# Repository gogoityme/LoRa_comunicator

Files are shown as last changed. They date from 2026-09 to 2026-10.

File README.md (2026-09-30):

# LoRa-comunicator

**For some reason I cant upload .history files to this repo so I uploaded it here: https://drive.google.com/drive/folders/1uOQKTIaHVd6gNlLYLUI4MQFI1cR0wfdA?usp=drive_link**

**Something about this project**

Okay so it all started with me watching some videos about meshcore and meshtastic. So I ordered one simple module (seeed studio xiao with LoRa module). Then I wanted something that would be like a standalone device with keyboard. I looked at some T-decks and told myself that it is quite expensive. So I started designing my own. That two versions that I made are using the same components so the BOM is the same but version V1.1 is using 5 more switches and diodes because of keyboard layout. And also the case would be aviliable on makerworld and in this repo (also with modified meshcore firmware) after I test the phisical product and I would have the rigt dimensions (I dont want to use dimensions shown on product websites, I simply dont trust them). BTW pictures are only from V1.1 because I think that this version is better.

**Build**

I have not ordered it yet but here would be updates 
All the placings you can do with BOM as reference.

# Some pictures from CAD and 3Drender

**Power management**

Snímka obrazovky 2026-09-27 191950

**Main "brain"**

Snímka obrazovky 2026-09-27 191911

**Keyboard**

Snímka obrazovky 2026-09-29 162724

**And 3D render with PCB-design**

Snímka obrazovky 2026-09-29 162827

Snímka obrazovky 2026-09-29 162906

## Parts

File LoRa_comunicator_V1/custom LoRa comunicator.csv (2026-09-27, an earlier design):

Reference | Qty | Value | Footprint | Price | Link
BT1 | 1 | Battery | Connector_JST:JST_PH_B2B-PH-K_1x02_P2.00mm_Vertical | 8€ | https://soldered.com/products/li-po-battery-2100mah-3-7v-903759-jst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
C1,C2 | 2 | 10nF | Capacitor_SMD:C_0805_2012Metric_Pad1.18x1.45mm_HandSolder | 0,03€ | https://www.tme.eu/sk/details/cl21b103kbannnc/kondenzatory-mlcc-smd/samsung/
C3 | 1 | 100nF | Capacitor_SMD:C_0805_2012Metric_Pad1.18x1.45mm_HandSolder | 0,03€ | https://www.tme.eu/sk/details/0805b104k500ct/kondenzatory-mlcc-smd/walsin/
D1,D2,D3,D4,D5,D6,D7,D8,D9,D10,D11,D12,D13,D14,D15,D16,D17,D18,D19,D20,D21,D22,D23,D24,D25,D26,D27,D28,D29,D30,D31,D32,D33,D34,D35,D36,D37,D38,D39,D40,D41,D42,D43,D44,D45 | 45 | D | Diode_SMD:D_SOD-123 | 0,1€ | https://www.tme.eu/sk/details/b140hw-7/diody-schottky-smd/diodes-incorporated/
D46 | 1 | 1N5819WS | Diode_SMD:D_SOD-123 | 0,1€ | https://www.tme.eu/sk/details/b140hw-7/diody-schottky-smd/diodes-incorporated/
J1 | 1 | USB_C_Receptacle_USB2.0_14P | Connector_USB:USB_C_Receptacle_G-Switch_GT-USB-7010ASV | 1,50€ | https://www.tme.eu/sk/details/usbc31srasmtbk/konektory-usb-a-ieee1394/adam-tech/usb-c31-s-ra-smt-bk/
Q1 | 1 | AO3401A | Package_TO_SOT_SMD:SOT-23 | 0,2 | https://www.tme.eu/sk/details/ao3401a/tranzistory-s-kanalom-p-smd/alpha-omega-semiconductor/
R1,R2 | 2 | 5.1k | Resistor_SMD:R_0805_2012Metric_Pad1.20x1.40mm_HandSolder | 0,018€ | https://www.tme.eu/sk/details/erj6geyj512v/rezistory-smd/panasonic/
R3 | 1 | 2.4k | Resistor_SMD:R_0805_2012Metric_Pad1.20x1.40mm_HandSolder | 0,015€ | https://www.tme.eu/sk/details/wr08x2401ftl/rezistory-smd/walsin/
R4,R5 | 2 | 4.7k | Resistor_SMD:R_0805_2012Metric_Pad1.20x1.40mm_HandSolder | 0,016€ | https://www.tme.eu/sk/details/wr08x4701ftl/rezistory-smd/walsin/
R6,R7,R8 | 3 | 10k | Resistor_SMD:R_0805_2012Metric_Pad1.20x1.40mm_HandSolder | 0,06€ | https://www.tme.eu/sk/details/erjp06f1002v/rezistory-smd/panasonic/
R9 | 1 | 100k | Resistor_SMD:R_0805_2012Metric_Pad1.20x1.40mm_HandSolder | 0,05€ | https://www.tme.eu/sk/details/arm05btcw1003a/rezistory-smd/viking/
SW1,SW2,SW3,SW4,SW5,SW6,SW7,SW8,SW9,SW10,SW11,SW12,SW13,SW14,SW15,SW16,SW17,SW18,SW19,SW20,SW21,SW22,SW23,SW24,SW25,SW26,SW27,SW28,SW29,SW30,SW31,SW32,SW33,SW34,SW35,SW36,SW37,SW38,SW39,SW40,SW41,SW42,SW43,SW44,SW45 | 45 | SW_Push | Button_Switch_SMD:SW_SPST_TL3342 | 0,4€ | https://www.tme.eu/sk/details/tl3342f160qg/mikrospinace-tact/e-switch/
U1 | 1 | TP4056-42-ESOP8 | Package_SO:SOIC-8-1EP_3.9x4.9mm_P1.27mm_EP2.41x3.3mm_ThermalVias | 0,19€ | https://techfun.sk/produkt/nabijaci-modul-tp4056-samostatny-cip-sop8-1a/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
U2 | 1 | AP2112K-3.3 | Package_TO_SOT_SMD:SOT-23-5 | 0,2€ | https://www.tme.eu/sk/details/ap2112k-3.3trg1/stabilizatory-napatia-neregulovane-ldo/diodes-incorporated/
U3 | 1 | HT-CT62 | RF_Module:Heltec_HT-CT62 | 7€ | https://heltec.org/project/ht-ct62/
U4 | 1 | TCA8418RTWR | Package_DFN_QFN:QFN-24-1EP_4x4mm_P0.5mm_EP2.15x2.15mm | 1,22€ | https://www.mouser.sk/en/ProductDetail/Texas-Instruments/TCA8418RTWR?qs=OaSNdy%2FNfznRf6fiHyMJcA%3D%3D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
U5 | 1 | ER_OLEDM0.91_1x-I2C | SSD1306:128x64OLED | 3,45€ | https://www.drotik-elektro.sk/arduino-platforma/1569-iic-i2c-oled-displej-0-96-biely-128-x-64.html?cv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
U6 | 1 | USBLC6-2SC6 | Package_TO_SOT_SMD:SOT-23-6 | 0,26€ | https://www.tme.eu/sk/details/usblc6-2sc6/bezpecnostne-diody-rebriky/stmicroelectronics/

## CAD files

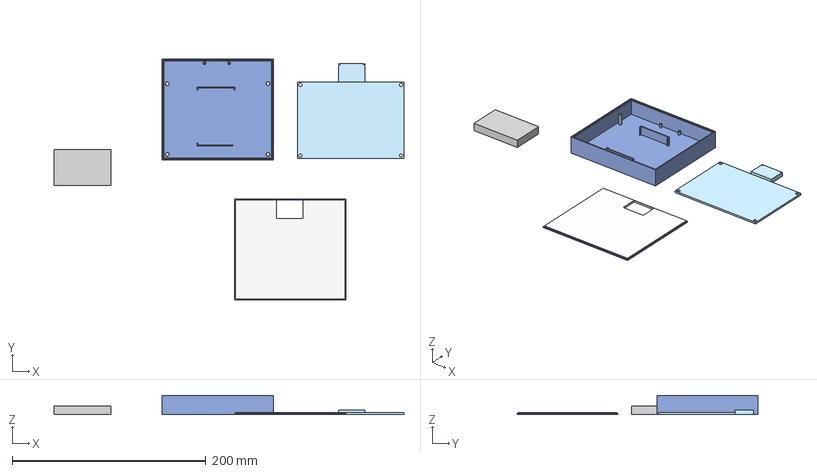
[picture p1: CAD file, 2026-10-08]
all parts.step
361.4 x 248.9 x 20.0 mm

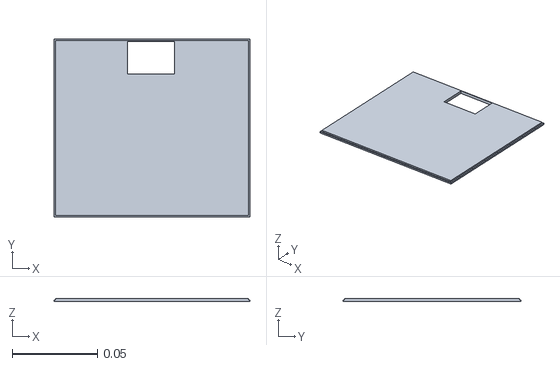
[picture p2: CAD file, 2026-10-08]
enclosure/top enclosure.stl
0.115 x 0.104 x 0.002

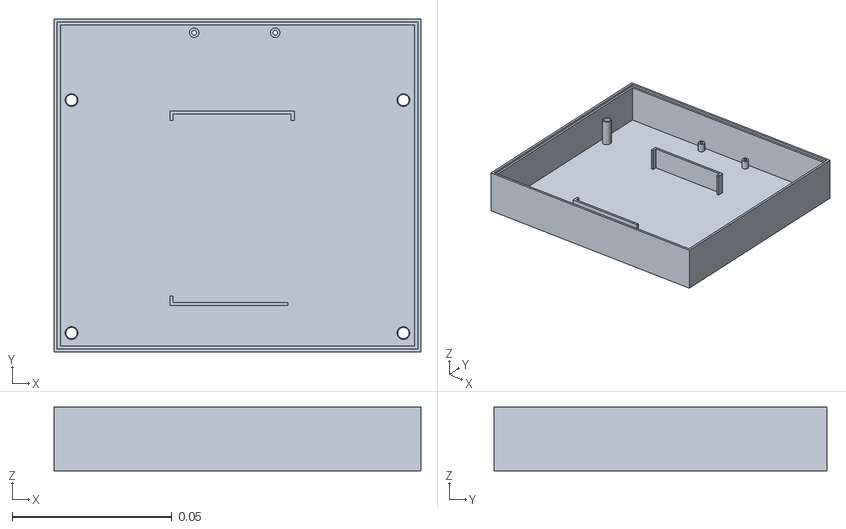
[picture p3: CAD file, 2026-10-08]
enclosure/bottom enclosure.stl
0.115 x 0.104 x 0.02

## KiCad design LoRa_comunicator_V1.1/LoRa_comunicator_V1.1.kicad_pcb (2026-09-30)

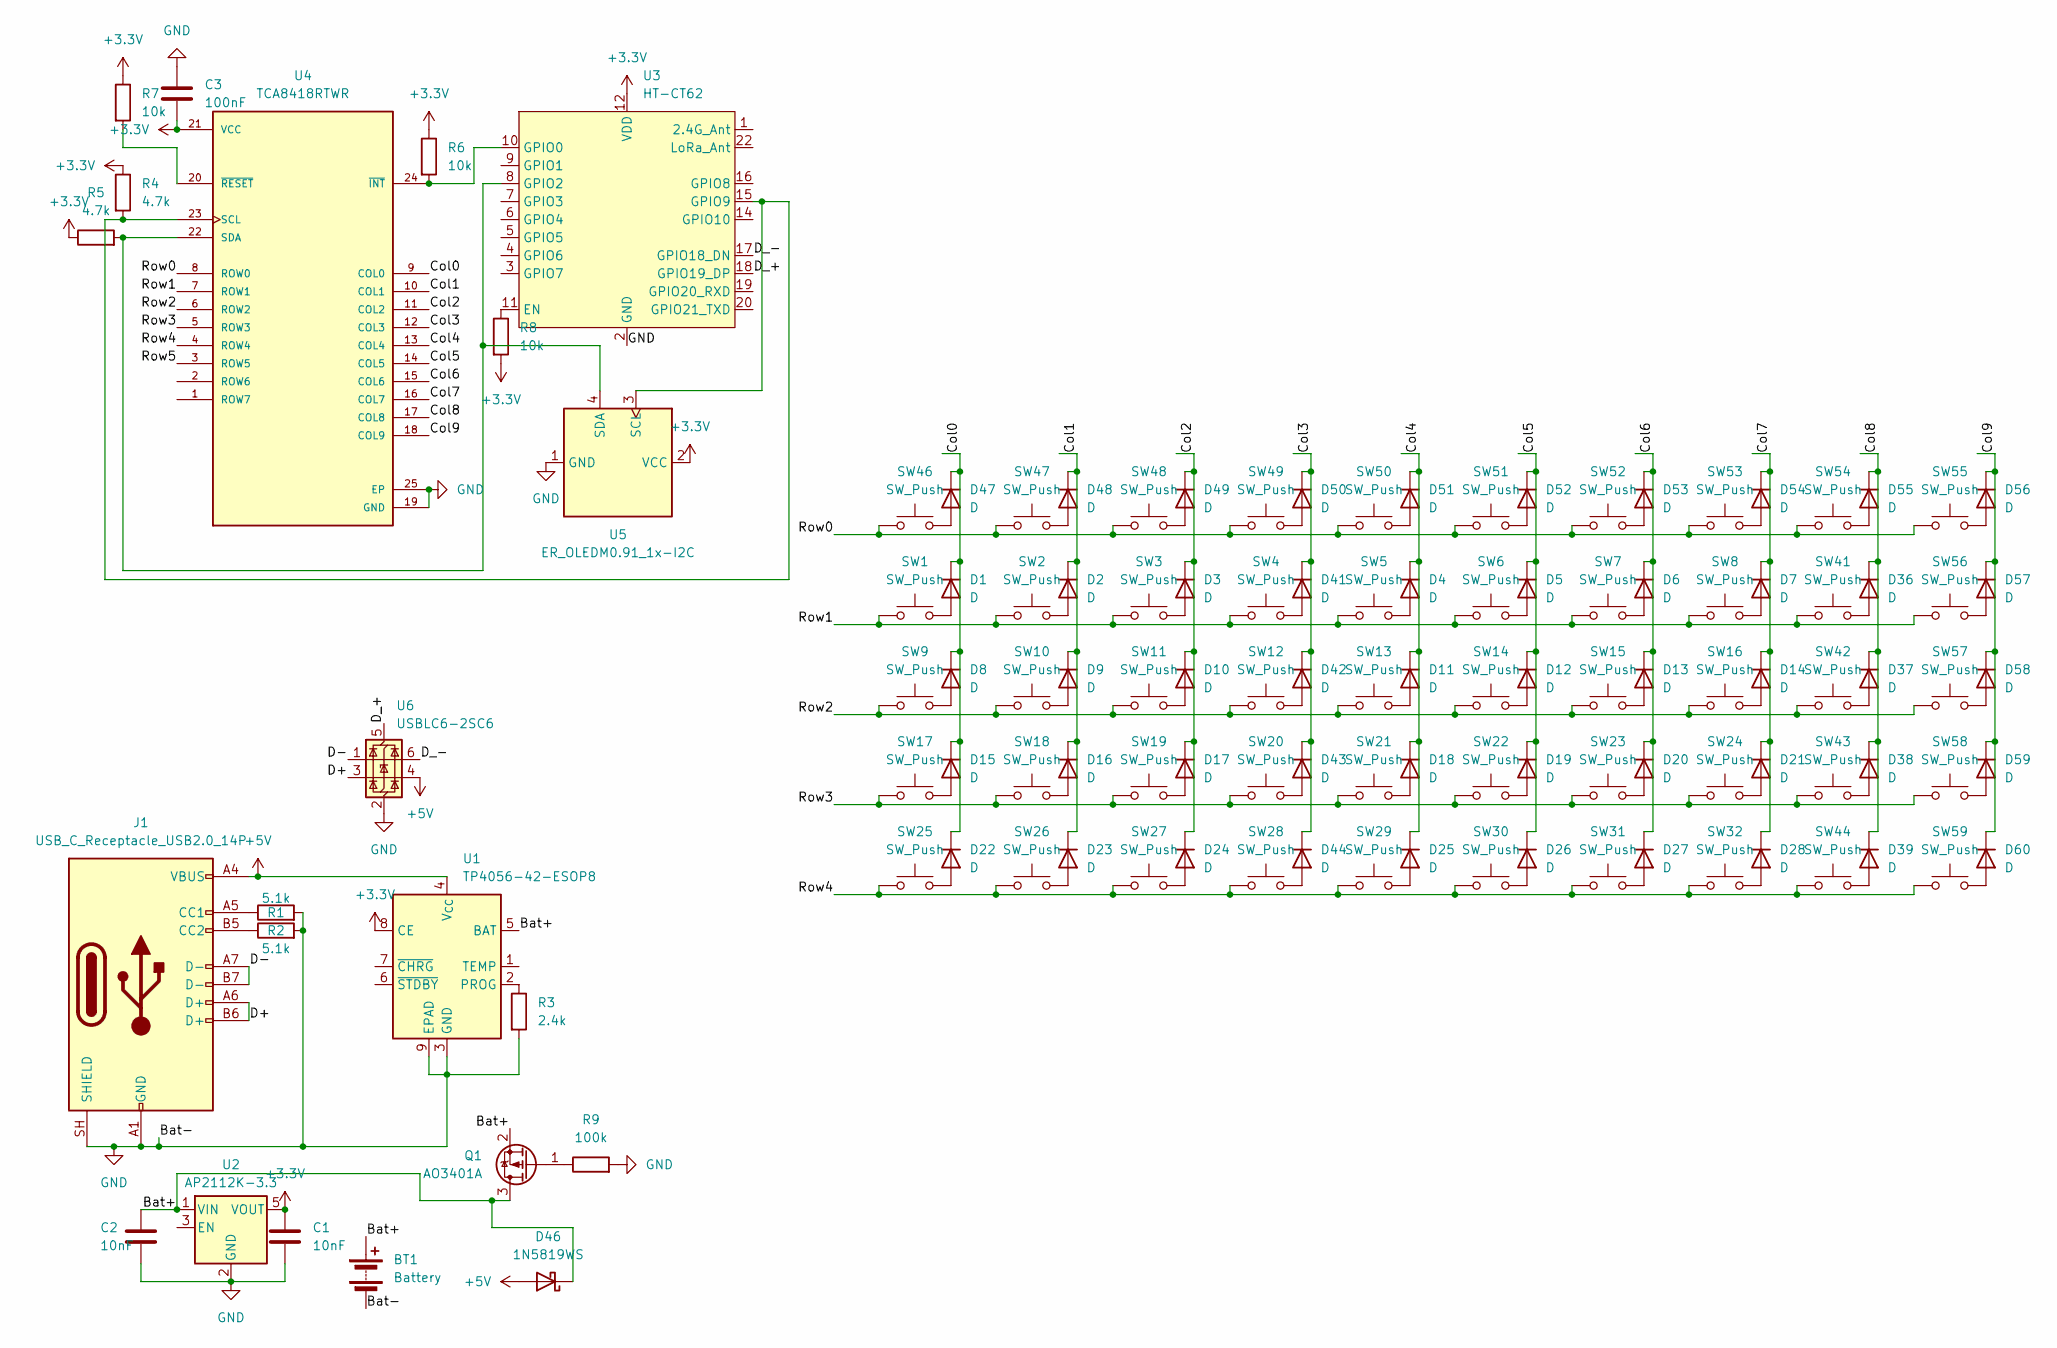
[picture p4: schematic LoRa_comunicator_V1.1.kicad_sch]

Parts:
BT1: Battery; JST_PH_B2B-PH-K_1x02_P2.00mm_Vertical
C1, C2: 10nF; C_0805_2012Metric_Pad1.18x1.45mm_HandSolder
C3: 100nF; C_0805_2012Metric_Pad1.18x1.45mm_HandSolder
D1, D2, D3, D4, D5, D6, D7, D8, D9, D10, D11, D12, D13, D14, D15, D16, D17, D18, D19, D20, D21, D22, D23, D24, D25, D26, D27, D28, D36, D37, D38, D39, D41, D42, D43, D44, D47, D48, D49, D50, D51, D52, D53, D54, D55, D56, D57, D58, D59, D60: D; D_SOD-123
D46: 1N5819WS; D_SOD-123
J1: USB_C_Receptacle_USB2.0_14P; USB_C_Receptacle_G-Switch_GT-USB-7010ASV
Q1: AO3401A; SOT-23
R1, R2: 5.1k; R_0805_2012Metric_Pad1.20x1.40mm_HandSolder
R3: 2.4k; R_0805_2012Metric_Pad1.20x1.40mm_HandSolder
R4, R5: 4.7k; R_0805_2012Metric_Pad1.20x1.40mm_HandSolder
R6, R7, R8: 10k; R_0805_2012Metric_Pad1.20x1.40mm_HandSolder
R9: 100k; R_0805_2012Metric_Pad1.20x1.40mm_HandSolder
SW1, SW2, SW3, SW4, SW5, SW6, SW7, SW8, SW9, SW10, SW11, SW12, SW13, SW14, SW15, SW16, SW17, SW18, SW19, SW20, SW21, SW22, SW23, SW24, SW25, SW26, SW27, SW28, SW29, SW30, SW31, SW32, SW41, SW42, SW43, SW44, SW46, SW47, SW48, SW49, SW50, SW51, SW52, SW53, SW54, SW55, SW56, SW57, SW58, SW59: SW_Push; SW_SPST_TL3342
U1: TP4056-42-ESOP8; SOIC-8-1EP_3.9x4.9mm_P1.27mm_EP2.41x3.3mm_ThermalVias
U2: AP2112K-3.3; SOT-23-5
U3: HT-CT62; Heltec_HT-CT62
U4: TCA8418RTWR; QFN-24-1EP_4x4mm_P0.5mm_EP2.15x2.15mm; PARTREV G
U5: ER_OLEDM0.91_1x-I2C; 128x64OLED
U6: USBLC6-2SC6; SOT-23-6

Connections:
+3.3V: C1.1, C3.2, R4.1, R5.1, R6.1, R7.1, R8.2, U1.8 (CE), U2.5 (VOUT), U3.12 (VDD), U4.21 (VCC), U5.2 (VCC)
+5V: D46.2 (A), J1.A4 (VBUS), J1.A9 (VBUS), J1.B4 (VBUS), J1.B9 (VBUS), U1.4 (V_{CC}), U6.4 (I/O2)
/Bat+: BT1.1 (+), C2.1, D46.1 (K), Q1.2 (S), Q1.3 (D), U1.5 (BAT), U2.1 (VIN)
/Col0: D1.1 (K), D8.1 (K), D15.1 (K), D22.1 (K), D47.1 (K), U4.9 (COL0)
/Col1: D2.1 (K), D9.1 (K), D16.1 (K), D23.1 (K), D48.1 (K), U4.10 (COL1)
/Col2: D3.1 (K), D10.1 (K), D17.1 (K), D24.1 (K), D49.1 (K), U4.11 (COL2)
/Col3: D41.1 (K), D42.1 (K), D43.1 (K), D44.1 (K), D50.1 (K), U4.12 (COL3)
/Col4: D4.1 (K), D11.1 (K), D18.1 (K), D25.1 (K), D51.1 (K), U4.13 (COL4)
/Col5: D5.1 (K), D12.1 (K), D19.1 (K), D26.1 (K), D52.1 (K), U4.14 (COL5)
/Col6: D6.1 (K), D13.1 (K), D20.1 (K), D27.1 (K), D53.1 (K), U4.15 (COL6)
/Col7: D7.1 (K), D14.1 (K), D21.1 (K), D28.1 (K), D54.1 (K), U4.16 (COL7)
/Col8: D36.1 (K), D37.1 (K), D38.1 (K), D39.1 (K), D55.1 (K), U4.17 (COL8)
/Col9: D56.1 (K), D57.1 (K), D58.1 (K), D59.1 (K), D60.1 (K), U4.18 (COL9)
/D+: J1.A6 (D+), J1.B6 (D+), U6.3 (I/O2)
/D-: J1.A7 (D-), J1.B7 (D-), U6.1 (I/O1)
/D_+: U3.18 (GPIO19_DP), U6.5 (VBUS)
/D_-: U3.17 (GPIO18_DN), U6.6 (I/O1)
/Row0: SW46.1, SW47.1, SW48.1, SW49.1, SW50.1, SW51.1, SW52.1, SW53.1, SW54.1, SW55.1, U4.8 (ROW0)
/Row1: SW1.1, SW2.1, SW3.1, SW4.1, SW5.1, SW6.1, SW7.1, SW8.1, SW41.1, SW56.1, U4.7 (ROW1)
/Row2: SW9.1, SW10.1, SW11.1, SW12.1, SW13.1, SW14.1, SW15.1, SW16.1, SW42.1, SW57.1, U4.6 (ROW2)
/Row3: SW17.1, SW18.1, SW19.1, SW20.1, SW21.1, SW22.1, SW23.1, SW24.1, SW43.1, SW58.1, U4.5 (ROW3)
/Row4: SW25.1, SW26.1, SW27.1, SW28.1, SW29.1, SW30.1, SW31.1, SW32.1, SW44.1, SW59.1, U4.4 (ROW4)
/Row5: U4.3 (ROW5)
GND: BT1.2 (-), C1.2, C2.2, C3.1, J1.A1 (GND), J1.A12 (GND), J1.B1 (GND), J1.B12 (GND), J1.SH (SHIELD), R1.2, R2.2, R3.2, R9.2, U1.3 (GND), U1.9 (EPAD), U2.2 (GND), U3.2 (GND), U3.13 (GND), U3.21 (GND), U4.19 (GND), U4.25 (EP), U5.1 (GND), U6.2 (GND)
unnamed: D1.2 (A), SW1.2
unnamed: D2.2 (A), SW2.2
unnamed: D3.2 (A), SW3.2
unnamed: D4.2 (A), SW5.2
unnamed: D5.2 (A), SW6.2
unnamed: D6.2 (A), SW7.2
unnamed: D7.2 (A), SW8.2
unnamed: D8.2 (A), SW9.2
unnamed: D9.2 (A), SW10.2
unnamed: D10.2 (A), SW11.2
unnamed: D11.2 (A), SW13.2
unnamed: D12.2 (A), SW14.2
unnamed: D13.2 (A), SW15.2
unnamed: D14.2 (A), SW16.2
unnamed: D15.2 (A), SW17.2
unnamed: D16.2 (A), SW18.2
unnamed: D17.2 (A), SW19.2
unnamed: D18.2 (A), SW21.2
unnamed: D19.2 (A), SW22.2
unnamed: D20.2 (A), SW23.2
unnamed: D21.2 (A), SW24.2
unnamed: D22.2 (A), SW25.2
unnamed: D23.2 (A), SW26.2
unnamed: D24.2 (A), SW27.2
unnamed: D25.2 (A), SW29.2
unnamed: D26.2 (A), SW30.2
unnamed: D27.2 (A), SW31.2
unnamed: D28.2 (A), SW32.2
unnamed: D36.2 (A), SW41.2
unnamed: D37.2 (A), SW42.2
unnamed: D38.2 (A), SW43.2
unnamed: D39.2 (A), SW44.2
unnamed: D41.2 (A), SW4.2
unnamed: D42.2 (A), SW12.2
unnamed: D43.2 (A), SW20.2
unnamed: D44.2 (A), SW28.2
unnamed: D47.2 (A), SW46.2
unnamed: D48.2 (A), SW47.2
unnamed: D49.2 (A), SW48.2
unnamed: D50.2 (A), SW49.2
unnamed: D51.2 (A), SW50.2
unnamed: D52.2 (A), SW51.2
unnamed: D53.2 (A), SW52.2
unnamed: D54.2 (A), SW53.2
unnamed: D55.2 (A), SW54.2
unnamed: D56.2 (A), SW55.2
unnamed: D57.2 (A), SW56.2
unnamed: D58.2 (A), SW57.2
unnamed: D59.2 (A), SW58.2
unnamed: D60.2 (A), SW59.2
unnamed: J1.A5 (CC1), R1.1
unnamed: J1.B5 (CC2), R2.1
unnamed: Q1.1 (G), R9.1
unnamed: R3.1, U1.2 (PROG)
unnamed: R8.1, U3.11 (EN)
unnamed: R6.2, U3.10 (GPIO0), U4.24 (~INT)
unnamed: R5.2, U3.8 (GPIO2), U4.22 (SDA), U5.4 (SDA)
unnamed: R4.2, U3.15 (GPIO9), U4.23 (SCL), U5.3 (SCL)
unnamed: R7.2, U4.20 (~RESET)

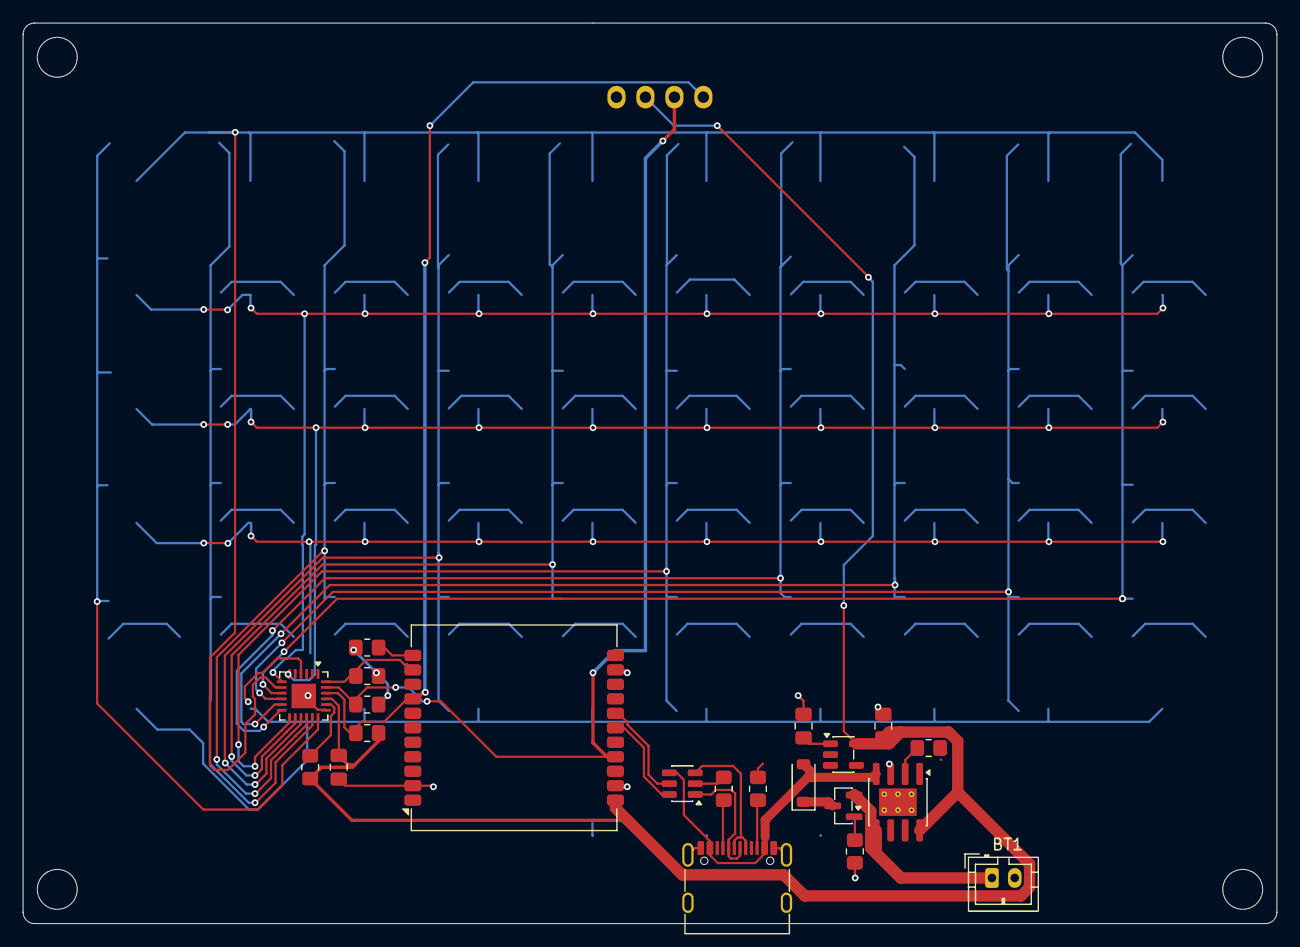
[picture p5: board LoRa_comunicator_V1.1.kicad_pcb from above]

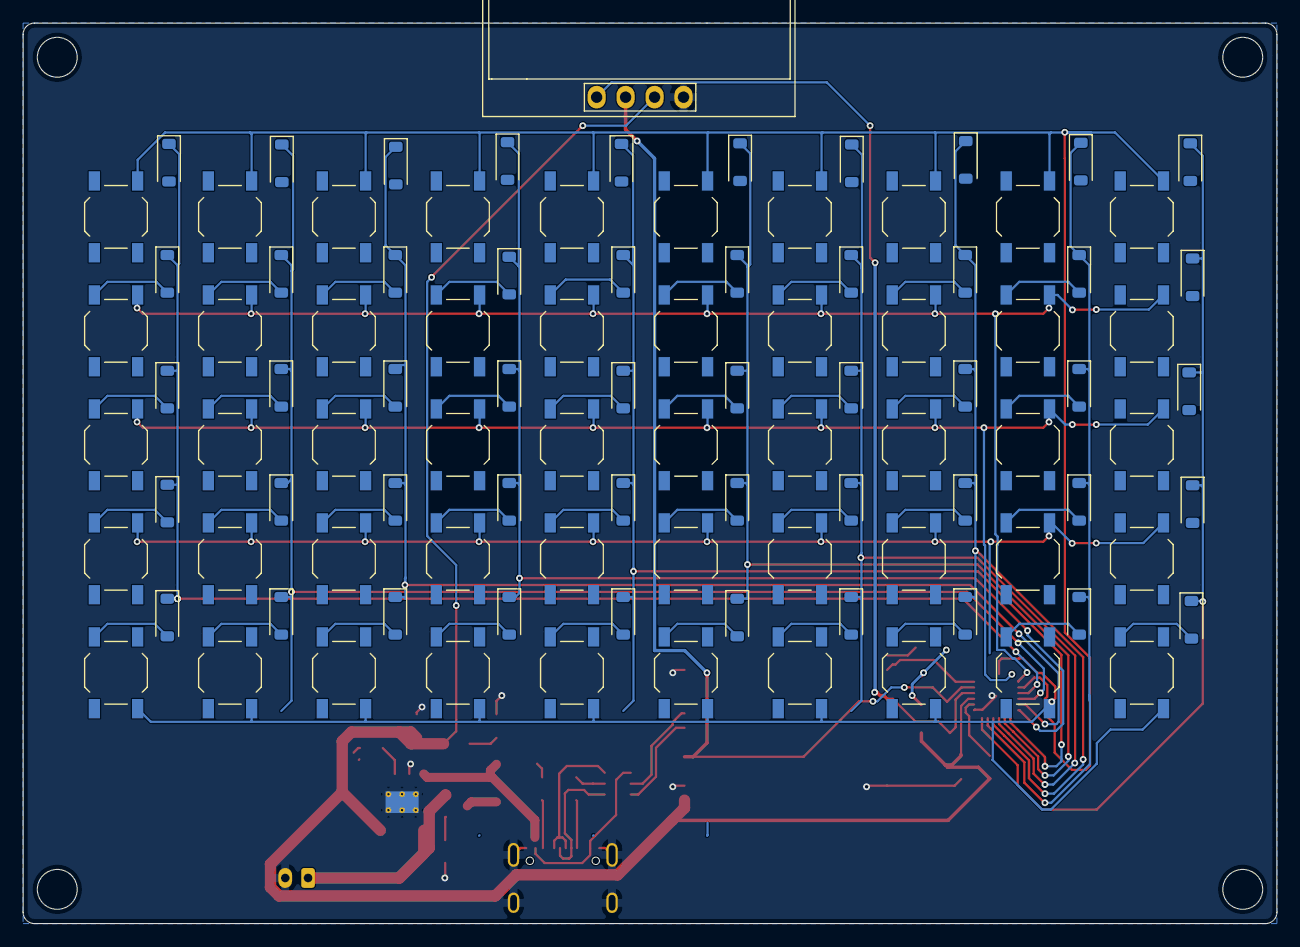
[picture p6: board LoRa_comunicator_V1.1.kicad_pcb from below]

Board: 2 copper layers, 110.0 x 79.0 mm, 122 parts (101 on the bottom side), 82 nets.

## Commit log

2026-09-24 Rename custom LoRa comunicator.csv to BOM.csv
    [BOM.csv]
2026-09-27 Update README with project details and images
    Added sections for build, power management, main components, and 3D render images.
2026-09-27 Update README with images and additional sections
    Added images and sections for power management, main brain, keyboard, and 3D render with PCB design.
2026-09-29 Update README with V1.1 section and images
    Added new version section with images and descriptions for power management, main brain, keyboard, and 3D render.
